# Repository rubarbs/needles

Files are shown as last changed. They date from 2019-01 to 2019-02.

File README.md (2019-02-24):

Needles
is a 1U Eurorack Midi Controller and Mutable Instruments Yarns Companion.

This module was designed to take full advantage of Yarn's capabilities. Most of Yarn's menu settings can be accessed and changed directly from Needles front panel, allowing for very fast and intuitive workflow.

needles

See the guides for more info.

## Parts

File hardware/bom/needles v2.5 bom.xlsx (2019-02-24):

NEEDLES v2.5 - BOM
Mouser Cart: https://www.mouser.com/ProjectManager/ProjectDetail.aspx?AccessID=fd577facc3
Parts | Qty | Description | Value | Package | MOUSER PART #
RESISTORS / CAPS
R27, R28 | 2 | RESISTOR, 1% | 51 Ohm | 0603 | 652-CR0603FX-51R0ELF
R13, R14 | 2 | RESISTOR, 1% | 1K | 0603 | 652-CR0603FX-1001ELF
R9, R12, R17, R18 | 4 | RESISTOR, 1% | 10K | 0603 | 652-CR0603FX-1002ELF OR 667-ERJ-3EKF1002V
R10, R11 | 2 | RESISTOR, 1% | 4.7K | 0603 | 652-CR0603FX-4701ELF
R15, R16, R19, R20, R21, R22, R23, R47, R48, R51, R52, R53, R54, R55, R56, R57, R58, R59, R60, R61, R62, R63, R68 | 23 | RESISTOR, 1% | 220 Ohm | 0603 | 652-CR0603FX-2200ELF
C2, C3 | 2 | CAPACITOR, ceramic | 22pf | 0603 | 81-GRM185C1H220JA01J or 80-C0603C220J5G7411
C1, C4, C5, C8, C9 | 5 | CAPACITOR, ceramic | 100n | 0603 | 81-GRM188R61C104KA1D
C6, C7 | 2 | CAPACITOR, electrolytic | 22u | PANASONIC C | 667-EEE-FP1E220AR
ICS / OTHER
L1 | 1 | Ferrite Bead |  | 0603 | 710-742792642
D2 | 1 | 1N5819HW diode | 1N5819HW | SOD123 | 621-1N5819HW-F
IC1, IC2, IC3 | 3 | MCP23017-E/SS I/O expander | MCP23017SS | SSOP28 | 579-MCP23017-E/SS
IC5 | 1 | LM1117-3.3V LDO Vreg | REG1117 | SOT223 | 926-LM1117MPX3.3NOPB
IC6 | 1 | CD4051 8-1 multiplexer | 4051PW | TSSOP16 | 595-CD4051BPWR
Y1 | 1 | 16MHz Crystal | 16MHz | CRYSTAL-SMD-5X3.2-4PAD | 815-ABM3B-16-B2
U1 | 1 | ATMega328p | ATMEGA328P | TQFP32-08 | 556-ATMEGA328P-AU
Q1, Q2 | 2 | 2n3906 Transistor | MMBT3906LT1G | MMBT3906LT1G | 863-MMBT3906LT1G
SWITCHES / BUTTONS
SW1 | 1 | Push-button, Yellow | Rest | C&K - Yellow | 611-D6R30F1LFS
SW2 | 1 | Push-button, Blue | Tie | C&K - Blue | 611-D6R60F1LFS
SW3 | 1 | Push-button, Green | Slide | C&K - Green | 611-D6R50F1LFS
SW4, SW5, SW6, SW7, SW8, SW9, SW10, SW11, SW12, SW13, SW14, SW15, SW16, SW17, SW18, SW19, SW20, SW21, SW24, SW25 | 20 | Push-button | 18 Keyboard 2 Octave | E-switch TL2201OAYA | 612-TL2201
SW Caps - Keyboard - 11 white / 7 Gray | 18 | Cap Round - 3.3mm shaft size | Keyboard caps | C&K | black 611-21125, white 611-F0202, gray 611-F0204
SW Caps - Octave - 2 red | 2 | Cap Rectangle - 3.3mm shaft size | octave | C&K | 611-F1203 (OR Selco PB 07/50/000)
S1, S2, S3, S7 | 5 | Tact Switch, 6mm | midi, legato, 3, 7, xtra | E-Switch - TL1105SPF160Q | 612-TL1105SP
Tact Switch Caps | 5 | Tact Caps 2.8mm shaft size | midi, legato, 3, 7, xtra |  | SELCO PB 10/51/000 - these are longer
S4 | 1 | Pushbutton - SPST - w/ LED | Shift | E-Switch - LP15S1WHTRED-N | 612-LP15S1WHTRED-N
S6 | 1 | Toggle switch, on-off-on | OSC-DEF-4T | C&K | 5mm actuator: 611-1103M2S3CQE2 12mm actuator: 611-1103M2S6CBE2 or NKK 633-M201303 (but needs round panel cutout)
LED
LED1, LED2, LED3, LED4, LED5, LED9 | 6 | LED 3mm, Red/Green, 3 terminals | Octave, arp |  | 604-WP115VEGW
LED8 | 1 | LED 3mm, 2 terminals | Legato |  | Red - 604-WP710A10ID, Green - 604-WP710A10GD
DISP1 | 1 | 7 Segment Display Green | Values |  | 755-LA-401MD OR 630-HDSP-F501
DISP2 | 1 | 7 Segment Display Red | Midi Channel |  | 755-LA-401VD OR 630-HDSP-F151
POTENTIOMETERS
R1, R2, R3, R4, R5, R6, R7, R8 | 8 | 10k linear pot, 25mm shaft with marker | 10K |  | Erthenvar , Thonk (https://erthenvar.myshopify.com/collections/9mm-potentiometers/products/9mm-vertical-panel-trimmer#)
VR1 | 1 | Slide Potentiometer | 10k |  | 652-PTA20432015CPB10
Slider cap | 1 | Slider Cap | optional |  | White - 633-AT4003B / Red - 633-AT4003C / Yellow - 633-AT434E
VARIOUS
J1, J3 | 2 | 2x3 Male Header 2.54mm | Power and ICSP | Amphenol/FCI | 649-67996-172HLF (this one is 2x36)
JP2 | 1 | 1x3 Male Header 2.54mm | MIDI |  | 649-77311-118-03LF (3 pin) 649-77311-118-24LF (24 pin)
Female Headers | 2 | 12x5 Female SMD Header | For displays |  | 517-9662102000ARPR
Servo cable | 1 | Female to Male | MIDI out —> Yarns MIDI In | Adafruit | 485-972
H1, H2, H3, H4, H5, H6, H7, H8, H9, H10 | 9 | Hex Stand Off 12mm x 5mm |  | Harwin | 4-40: 855-R44-1001202 M2.5: 855-R25-1001202
Screws for Stand offs | 18 | Flat Head screws |  | Mcmaster | 4-40: https://www.mcmaster.com/#96640A054 M2.5: https://www.mcmaster.com/91698a242

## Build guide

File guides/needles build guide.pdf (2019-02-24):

## NEEDLES v2.5 DIY Build Instructions

Hi, thanks for building this module. Please go through this entire doc prior to building, especially the pictured steps below. Some components need some prep before soldering and some should be soldered with the panel screwed in so that they align correctly and are the correct height off the PCB. I solder in this order starting with SMD:

- All IC’s (both sides of pcb)
- Resistors
- Caps
- Thru-hole headers (facing the bottom)
- Upload software
- Check 3.3v
- Keyboard/Octave switches (After gluing caps. Must be flush with PCB. Solder one leg, then while pressing down on the switch, heat the leg again to make sure switch is flush with pcb. Solder the rest of the legs.
- The rest of the components following the pictured tips below:

SCROLL DOWN

\ | /
\ | /
\/

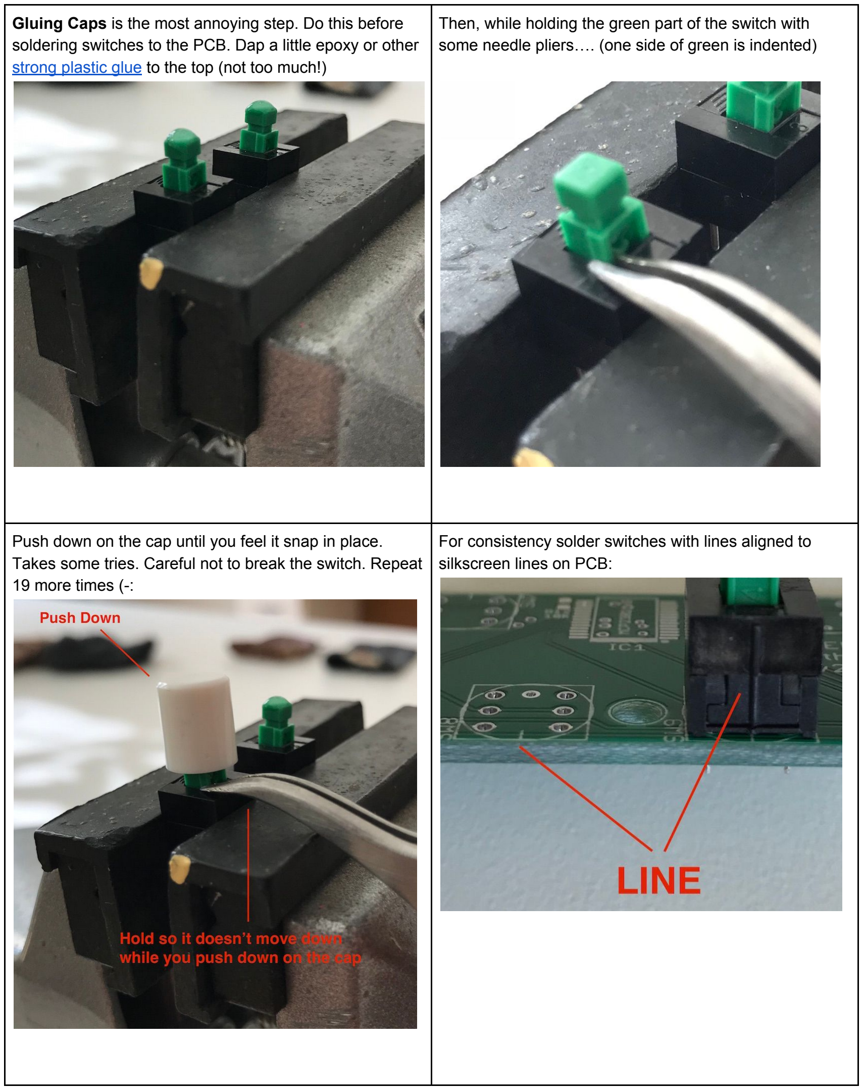
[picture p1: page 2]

Gluing Caps is the most annoying step. Do this before soldering switches to the PCB. Dap a little epoxy or other strong plastic glue (https://www.amazon.com/J-B-Weld-50132-PlasticWeld-Quick-Setting/dp/B009EU5ZMK?s=automotive) to the top (not too much!)

Then, while holding the green part of the switch with some needle pliers…. (one side of green is indented)

Push down on the cap until you feel it snap in place. Takes some tries. Careful not to break the switch. Repeat 19 more times (-:

For consistency solder switches with lines aligned to silkscreen lines on PCB:

Led Segments. You might think of a different technique. It’s possible to skip the female headers and just solder the male headers to the perf board. Play around with it if you like.
Locate parts and repeat these steps for both
segments. I sent the perf board thingies with the pcb

Stack parts. Solder the 10 legs, joining segment and male headers together. Making sure all the pieces are perfectly flush! Solder one leg, then while pressing down, heat the leg again to make sure it’s all flush. Solder the remaining legs.

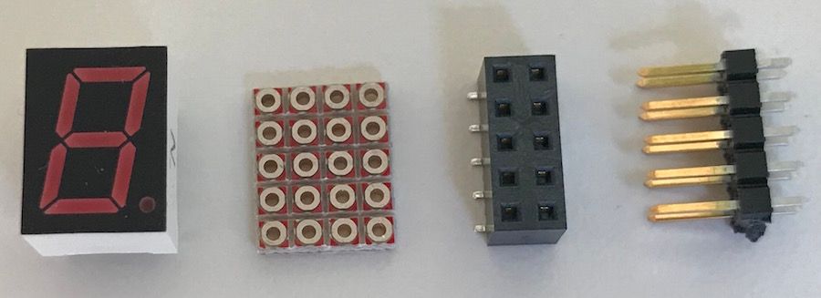
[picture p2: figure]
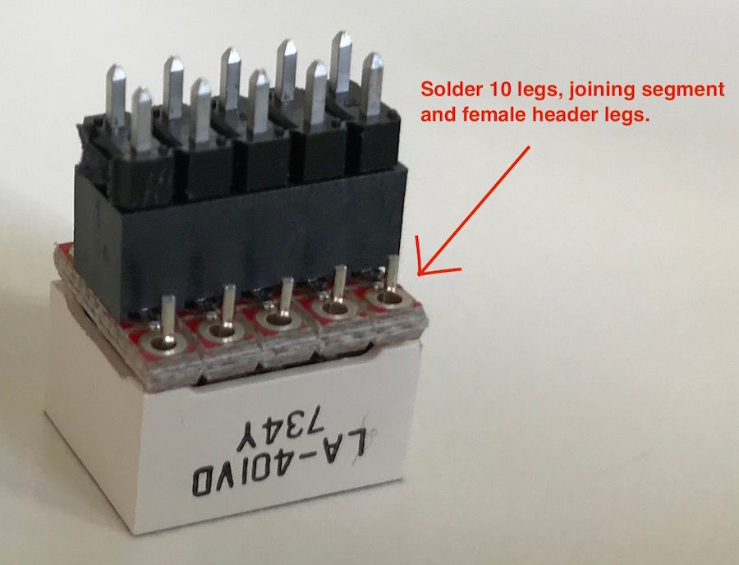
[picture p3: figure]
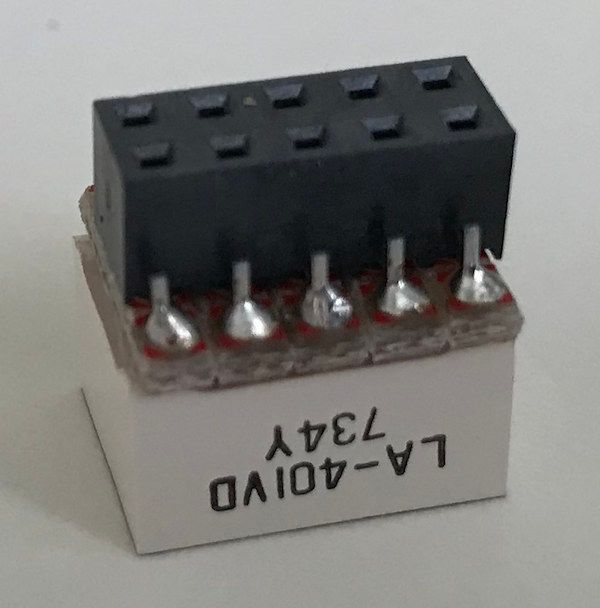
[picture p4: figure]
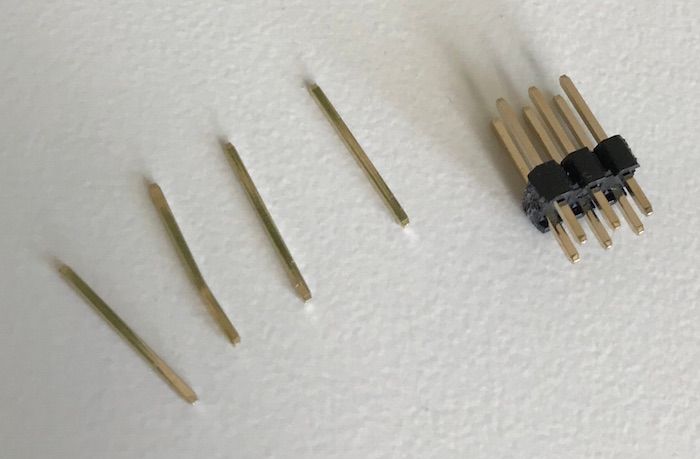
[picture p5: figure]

Remove 10 pin header: | Take out 10 header pins from the male header.

Push segment gently into panel so it’s flat with the panel front:

Secure panel to PCB. Insert the loose headers you removed one by one into the segment’s female header. Make sure again the segment is sitting flat, and solder headers.

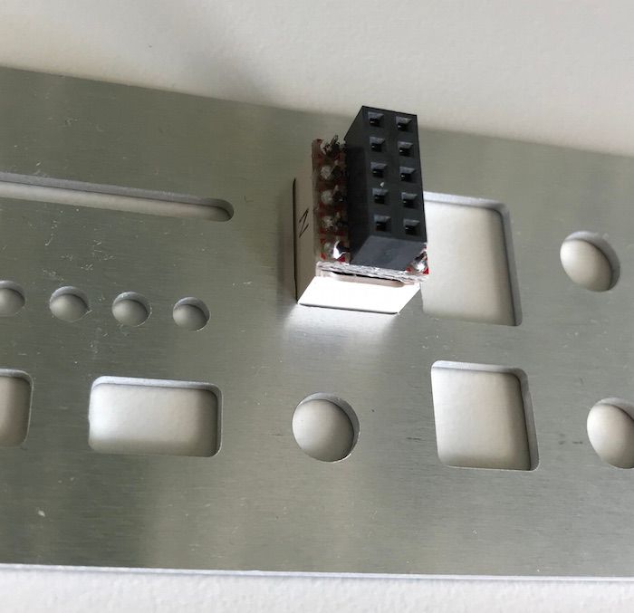
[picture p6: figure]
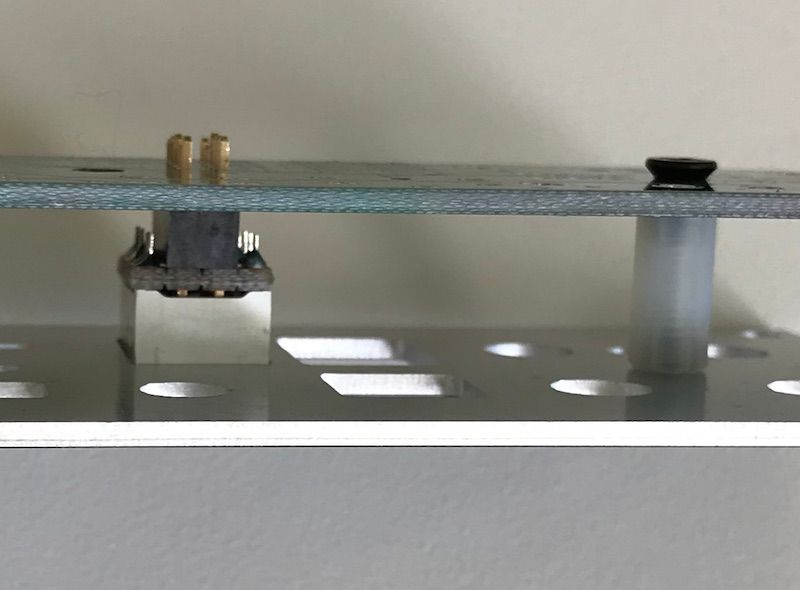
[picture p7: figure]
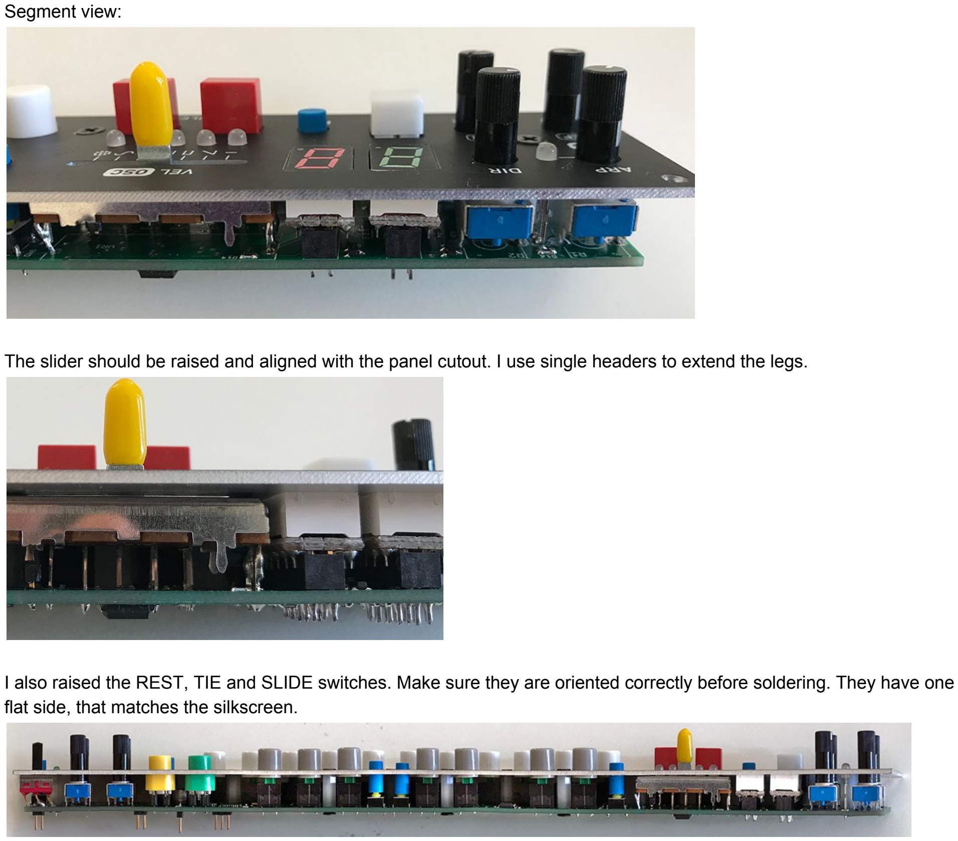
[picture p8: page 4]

Segment view:

The slider should be raised and aligned with the panel cutout. I use single headers to extend the legs.

I also raised the REST, TIE and SLIDE switches. Make sure they are oriented correctly before soldering. They have one flat side, that matches the silkscreen.

Back of PCB. Servo motor cable going to Yarns MIDI IN. Power says +5V but you can give it +12V.

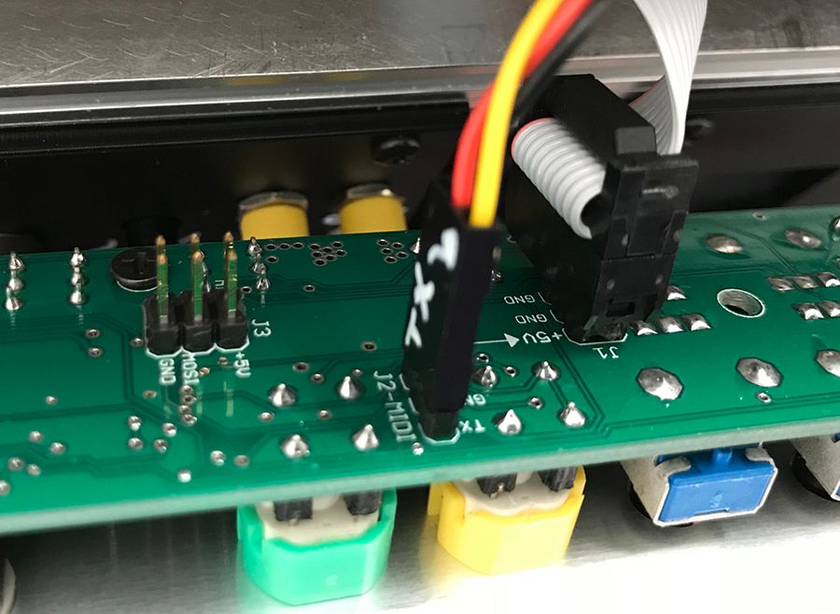
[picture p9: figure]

I solder MIDI wires to the back of Yarns. You could make a little 1U panel with a MIDI jack and connect to the front:

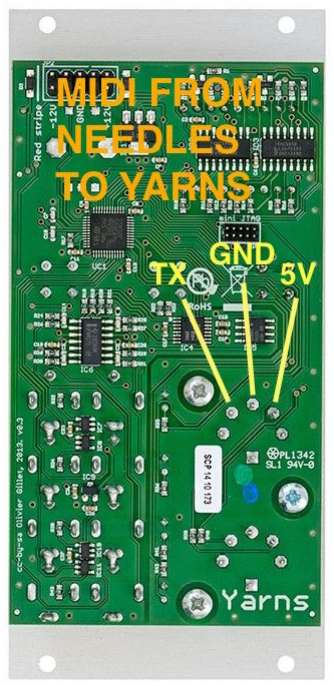
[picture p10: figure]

Software:
Written in Arduino. Download “Needles_v2.4_2.ino” located in the Software folder. Download two libraries for Arduino using the Library Manager or directly - the MIDI Library, (https://github.com/FortySevenEffects/arduino_midi_library/releases/tag/4.3.1) and Adafruit MCP23017 Library. (https://github.com/adafruit/Adafruit-MCP23017-Arduino-Library) Place them in the correct folders. Connect your programmer to the ICSP Header. (I use an Olimex AVR ISP MKII).
Choose Arduino/Genuino UNO Board (Ensures the correct fuses are set)

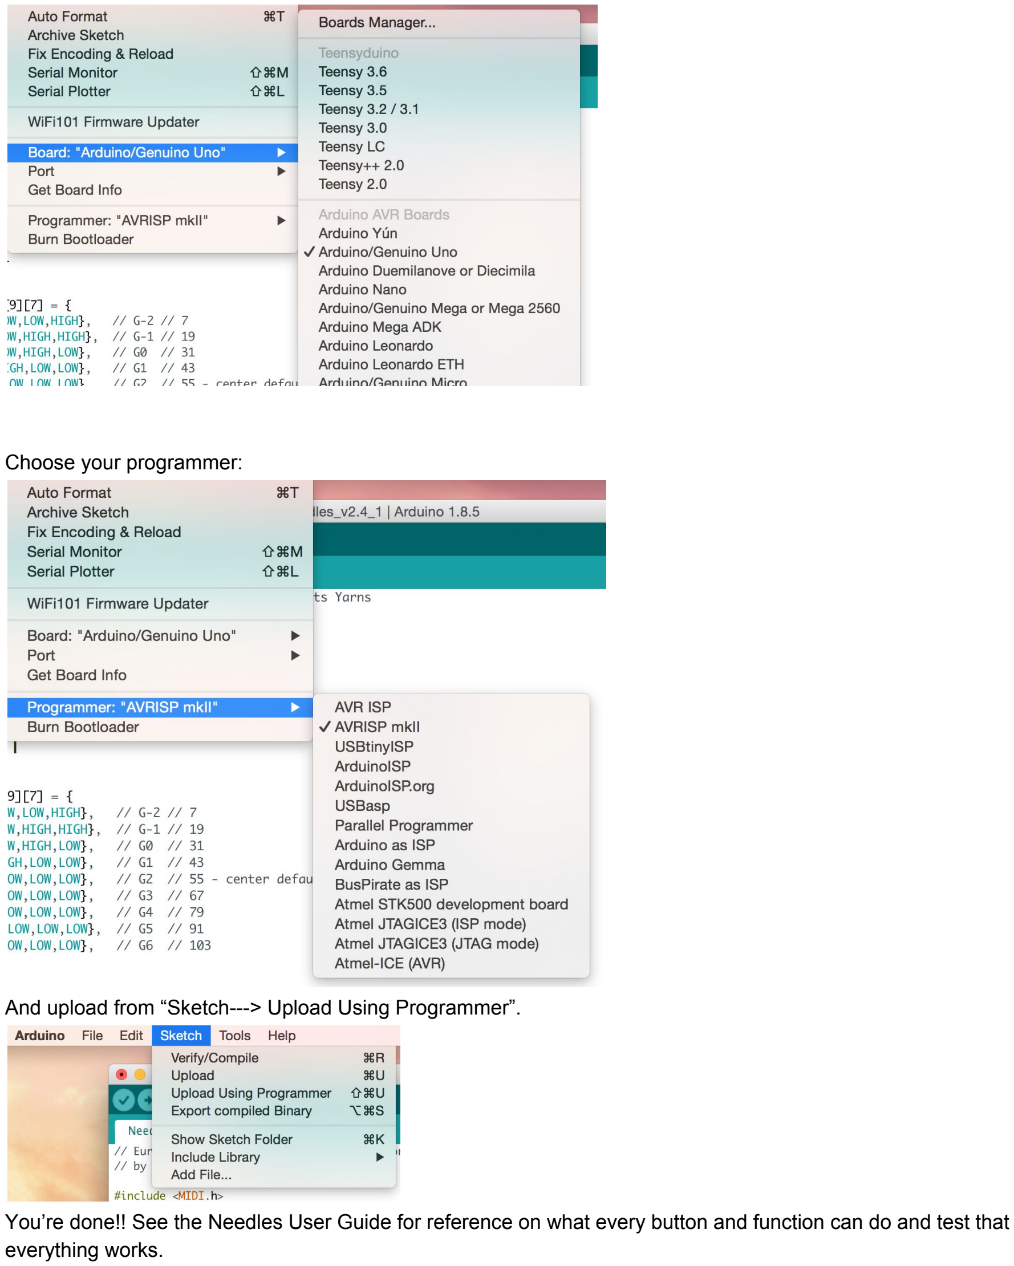
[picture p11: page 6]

Choose your programmer:

And upload from “Sketch---> Upload Using Programmer”.

You’re done!! See the Needles User Guide for reference on what every button and function can do and test that everything works.

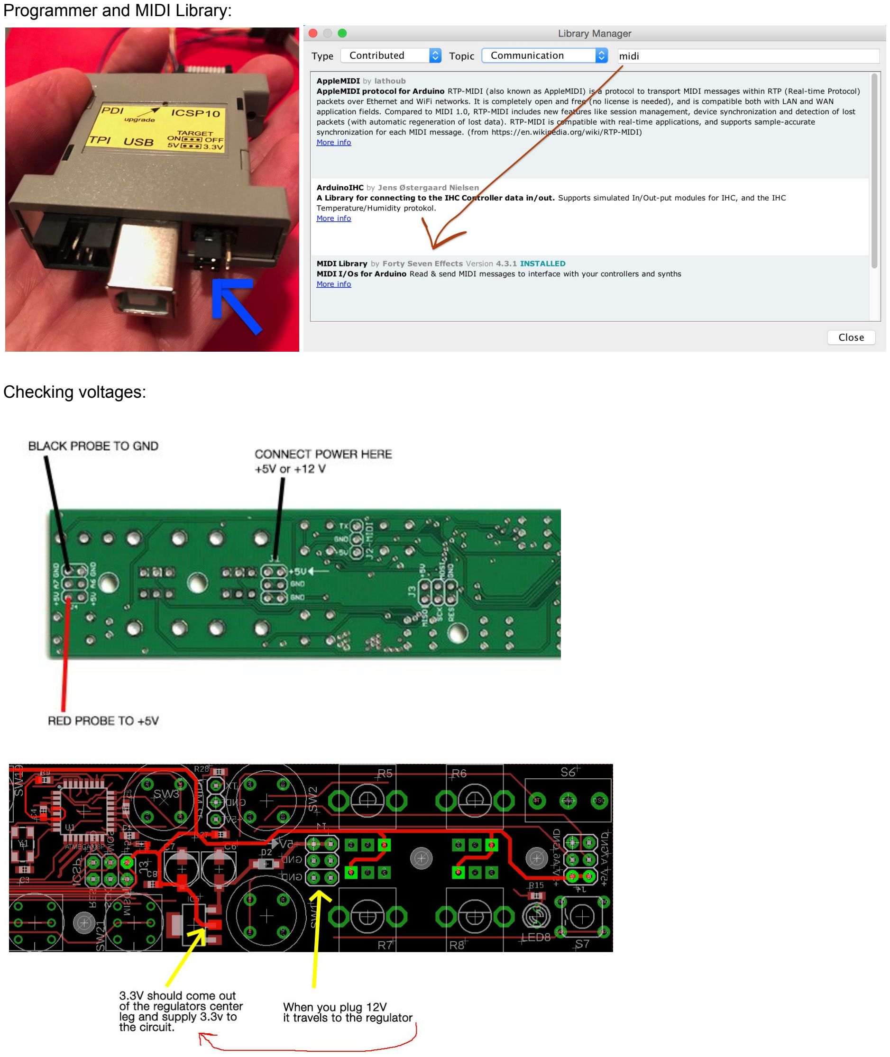
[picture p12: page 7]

Programmer and MIDI Library:

Checking voltages:

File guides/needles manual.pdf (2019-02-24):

Needles v2.5 Manual

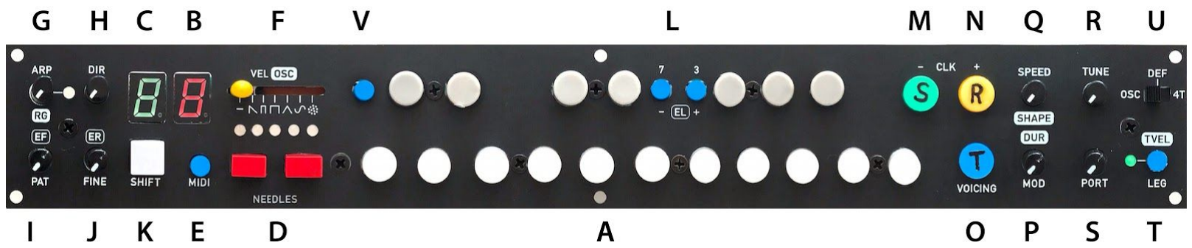
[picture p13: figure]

A. Keyboard: G2-C4. Full range is G-2 to C8. Will also transpose any recorded sequence. See “MIDI” for latching
B. Red: MIDI channel segment. 1-4.
C. Green: Values segment.
D. Octaves: 4 up and 4 down. Press both Octave buttons at the same time to return to center.
E. MIDI - Channel selection 1-4. Pressing MIDI button while holding down note/notes will latch those notes. SHIFT will light up. To unlatch return to the latched MIDI channel and press any octave key. Temporary hack.
F. VEL/OSC - Velocity 0-127. In 1M mode velocity is recorded into a sequence and output on Yarns CV2. Try recording a different velocity for each note in your sequence and using CV2 output to modulate something. When “OSC mode” is on slider changes to Waveform selection.
G. ARP - Range “0-4”. “0” is off. Turns on at “1” with red LED. Turning with SHIFT turns on “Euclidean mode” with green LED. In “4T mode” used to turn on RG - Rhythm Generator.
H. DIR - Arp direction. Used also in “Euclidean mode”
I. PAT - Arp Pattern “1-22”. In “Euclidean mode” chooses Euclidean Fill “0-32”.
J. FINE - Fine tuning. In “Euclidean mode” chooses Euclidean Rotate “0-32".
K. SHIFT - Special functions and Latch indicator
L. 3 & 7 - When recording sequences in Yarns these will insert 3 or 7 ties. Together with SHIFT will insert 3 or 7 rests. In “Euclidean mode” will choose Euclidean Length -/+
a. 3 & 7 explained: Press “Record” on Yarns to record a sequence. It shows “step 01”
i. Insert any note in “step 01” from Needles.
ii. | Press “3”. You inserted 3 ties. Yarns will be on “step 5”.
iii. | Insert any note.
iv. | Press “7”. You inserted 7 rests. Yars will be on “step 13”.
v. Press “3”. You inserted 3 ties. Yarns will be on step “17”.
vi. | Press Record on Yarns exit recording. You recorded a 16 step sequence. This is how you can
| record sequences in Yarns super fast!
| 3 | | 7 | | 3
note | tie | tie | tie | note | tie | tie | tie | tie | tie | tie | tie | note | tie | tie | tie
1 | 2 | 3 | 4 | 5 | 6 | 7 | 8 | 9 | 10 | 11 | 12 | 13 | 14 | 15 | 16

vii. | Try inserting a kick on step 1, 5, 9, 13 by pressing 3 in between each one and exiting Yarns
| record mode on step 17. Takes 3 seconds (-:
M. SLIDE - Inserts a Slide. Legato must be turned on. Together with SHIFT chooses Sequence Clock Division “-”
N. REST - Inserts a Rest. Together with SHIFT chooses Sequence Clock Division “+”
O. TIE - Inserts a Tie. Together with SHIFT chooses Voicing (2P, 4P, 2>, 4>, 8>)
P. MOD - Vibrato. Independant for each channel. In “4T Mode” chooses Trigger Duration
Q. SPEED - Vibrato Speed. Independant for each channel. In “4T Mode” chooses Trigger Shape
R. TUNE - Tuning System 0-33.
S. PORT - Portamento. Only when Legato is off.
T. LEG - Legato on/off with LED indicator. Turn on for Slides. In “4T Mode” turns on Trigger Velocity Scale, used with Velocity Slider
U. OSC - DEF - 4T:
a. Default mode in center.
b. 4T mode changes SPEED, MOD, LEG, ARP to send 4T specific values. Remember that triggers in 4T come out of the Yarns CV outputs. Set the NO(TE) parameter to the trigger note you want for each Part. Default is “36, 38, 40, 42”. I recommend setting it to “60, 62, 64, 65” which means C3, D3, E3, F3 which is the center octave setting on Needles. Save your Layouts in Yarns too.
c. OSC mode turns on an oscillator and loads a Saw waveform to as many channels as your current Yarns setup allows. Velocity slider chooses between the waveform. For example:
i. On CV4 in monophonic mode (1M)
ii. | On CV3 and CV4 in duophonic modes (2M or 2P)
iii. | On CV1, CV2, CV3, CV4 in quadraphonic modes (4M or 4P)
This is great for using Yarns as a 4 channel oscillator module (each channel having it’s own unique waveform), or for fattening up sounds when sequencing in 1M and 2M modes - because CV3 or CV4 will play the exact same sequence that is recorded and sent out of CV1 and CV2.. So you can flip the OSC switch anytime and viola - you get one or two extra voices.
V. XTRA - button for something of your choice.

YARNS MIDI IMPLEMENTATION CHART: https://docs.google.com/spreadsheets/d/15TJX1dSbiRo1jPDxPYR4GV2ICQuVu5B6wAjiAAwP60o/pub?gid=1

Most of Yarns settings can be accessed from Needles. But to record sequences you need to work together with Yarns to enter “Record mode”. Choose the Layout you want in Yarns (1M, 2M, 4M etc..), and then choose if you want each Part to receive messages it’s own unique channel messages. For example, if you want Needles to control 4 different and unique channels:
- choose 4M layout on Yarns
- Set Part 1 to receive on Channel 1 - Needles channel 1 will control it
- Set Part 2 to receive on Channel 2 - Needles channel 2 will control it
- Set Part 3 to receive on Channel 3 - Needles channel 3 will control it
- Set Part 4 to receive on Channel 4 - Needles channel 4 will control it

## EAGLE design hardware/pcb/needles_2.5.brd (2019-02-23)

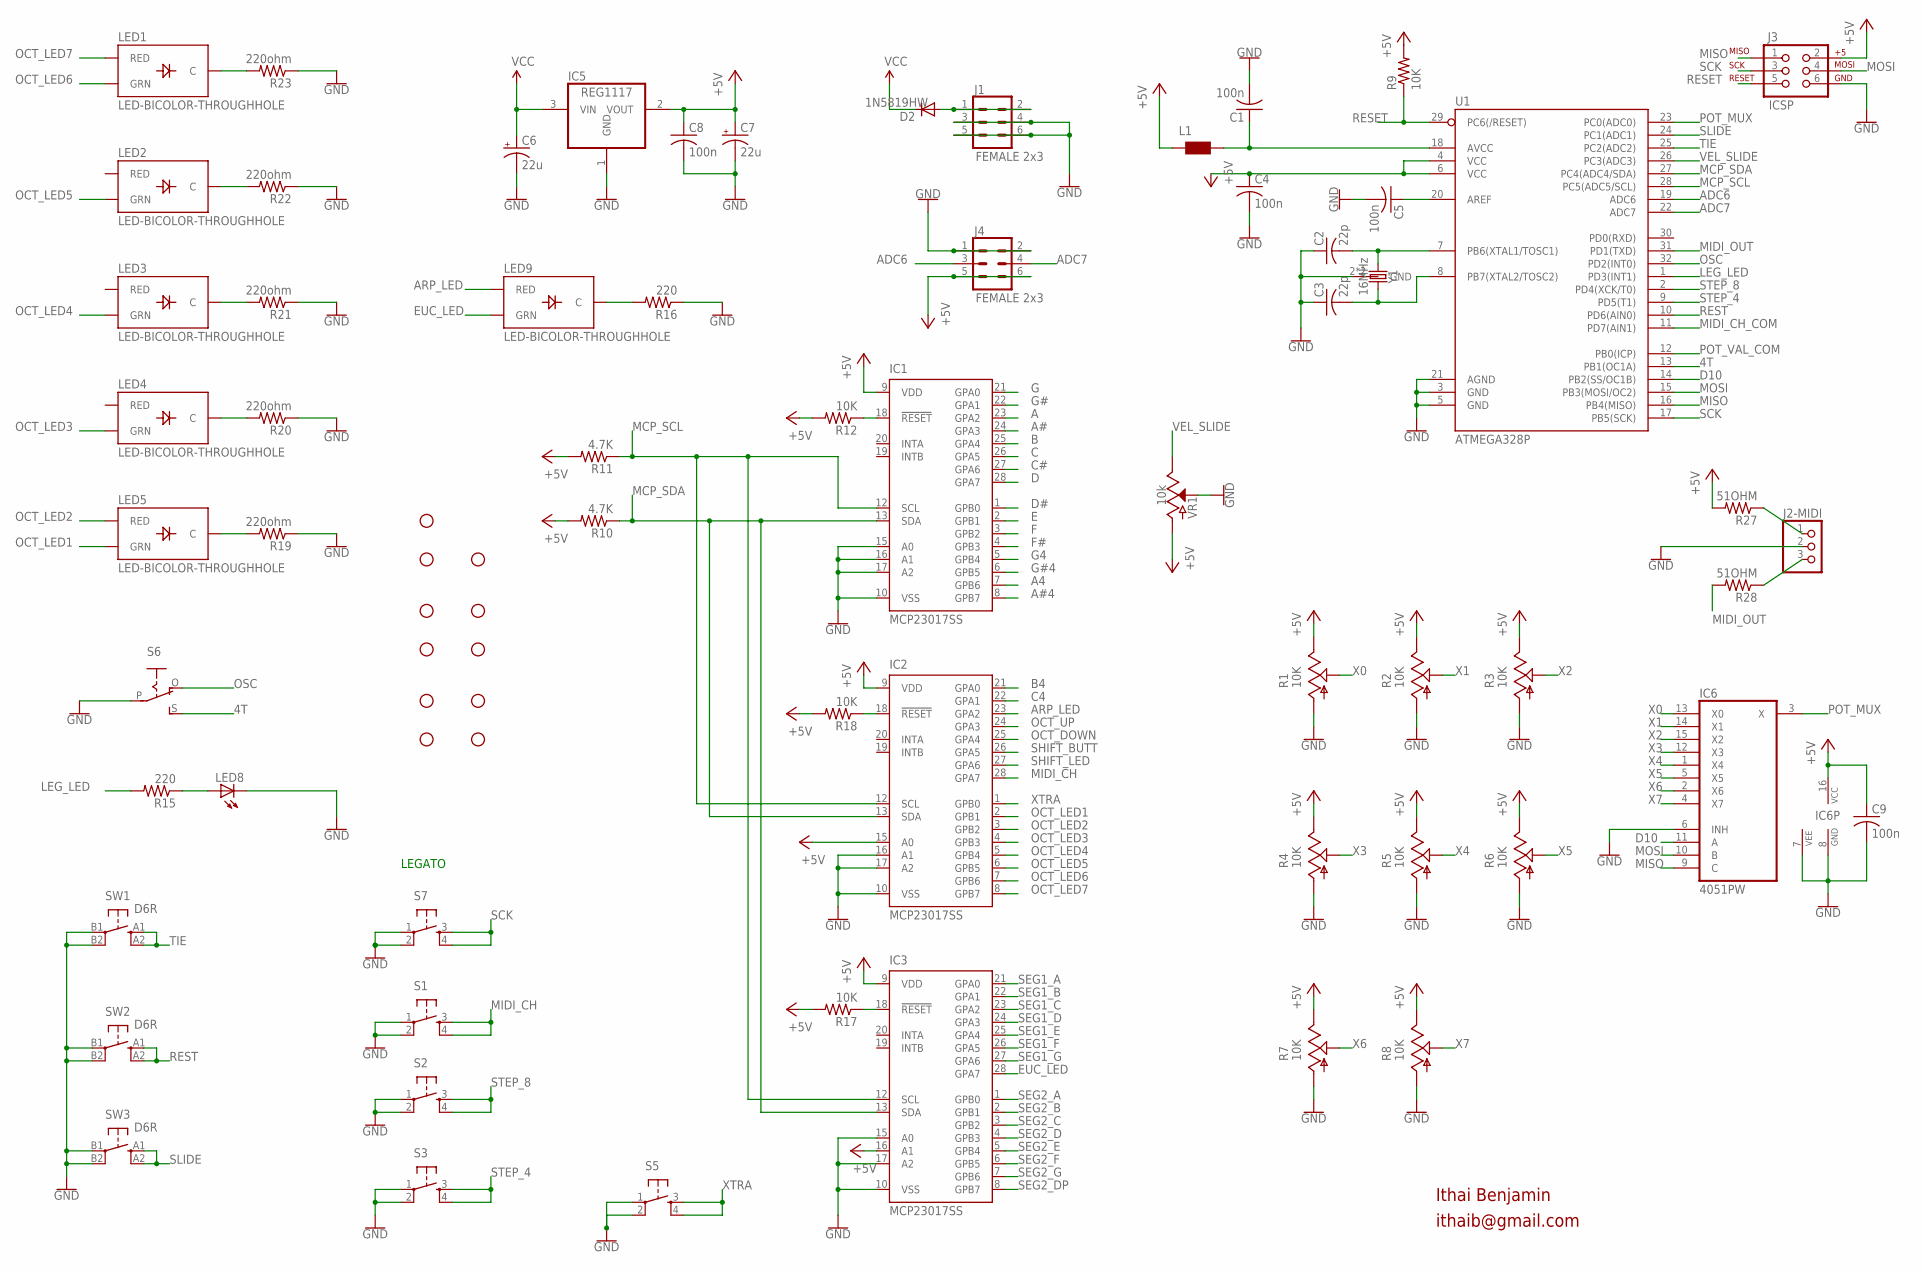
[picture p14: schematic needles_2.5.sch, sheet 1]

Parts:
C1, C4, C5, C8, C9: 100n; C0603
C2, C3: 22p; C0603
C6, C7: 22u; PANASONIC_C
D2: 1N5819HW; SOD123
H1, H2, H3, H4, H5, H6, H7, H8, H9, H10, H11: STAND-OFF
IC1, IC2, IC3: MCP23017SS; SSOP28
IC5: REG1117; SOT223
IC6: 4051PW; TSSOP16
J1, J4: FEMALE 2x3; 2X3
J2-MIDI: PINHD-1X3; 1X03
J3: ICSP; 2X3
L1: WE-CBF_0603; 0603
LED1, LED2, LED3, LED4, LED5, LED9: LED-BICOLOR-THROUGHHOLE
LED8: LED3MM
R1, R2, R3, R4, R5, R6, R7, R8: 10K; ALPS_POT_VERTICAL
R9, R12, R17, R18: 10K; R0603
R10, R11: 4.7K; R0603
R15, R16: 220; R0603
R19, R20, R21, R22, R23: 220ohm; R0603
R27, R28: 51OHM; R0603
S1, S2, S3, S5, S7: TAC_SWITCHPTH; TACTILE-PTH
S6: S-ON-ONSMALL_SLIDE; ES_100SP1T6B11M2QEH_SMALL
SW1, SW2, SW3: D6R
U1: ATMEGA328P; TQFP32-08
VR1: 10k; SLIDER-MEDIUM
Y1: 16MHz; CRYSTAL-SMD-5X3.2-4PAD

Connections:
4T: S6.S, U1.13 (PB1(OC1A))
+5V: C4.1, C7.+, C8.1, C9.1, IC1.9 (VDD), IC2.9 (VDD), IC2.15 (A0), IC3.9 (VDD), IC3.16 (A1), IC5.2 (VOUT), IC6.16 (VCC), J3.2, J4.5, J4.6, L1.1, R1.P$1 (E), R2.P$1 (E), R3.P$1 (E), R4.P$1 (E), R5.P$1 (E), R6.P$1 (E), R7.P$1 (E), R8.P$1 (E), R9.2, R10.2, R11.2, R12.2, R17.2, R18.2, R27.2, U1.4 (VCC), U1.6 (VCC), VR1.BOTTOM (A); also elsewhere on the board
A: IC1.23 (GPA2); also elsewhere on the board
A4: IC1.7 (GPB6); also elsewhere on the board
A#: IC1.24 (GPA3); also elsewhere on the board
A#4: IC1.8 (GPB7); also elsewhere on the board
ADC6: J4.3, U1.19 (ADC6)
ADC7: J4.4, U1.22 (ADC7)
AREF: C5.1, U1.20 (AREF)
ARP_LED: IC2.23 (GPA2), LED9.3 (RED)
B: IC1.25 (GPA4); also elsewhere on the board
B4: IC2.21 (GPA0); also elsewhere on the board
C: IC1.26 (GPA5); also elsewhere on the board
C4: IC2.22 (GPA1); also elsewhere on the board
C#: IC1.27 (GPA6); also elsewhere on the board
D: IC1.28 (GPA7); also elsewhere on the board
D10: IC6.11 (A), U1.14 (PB2(SS/OC1B))
D#: IC1.1 (GPB0); also elsewhere on the board
E: IC1.2 (GPB1); also elsewhere on the board
EUC_LED: IC3.28 (GPA7), LED9.1 (GRN)
F: IC1.3 (GPB2); also elsewhere on the board
F#: IC1.4 (GPB3); also elsewhere on the board
G: IC1.21 (GPA0); also elsewhere on the board
G4: IC1.5 (GPB4); also elsewhere on the board
G#: IC1.22 (GPA1); also elsewhere on the board
G#4: IC1.6 (GPB5); also elsewhere on the board
GND: C1.2, C2.1, C3.1, C4.2, C5.2, C6.-, C7.-, C8.2, C9.2, IC1.10 (VSS), IC1.15 (A0), IC1.16 (A1), IC1.17 (A2), IC2.10 (VSS), IC2.16 (A1), IC2.17 (A2), IC3.10 (VSS), IC3.15 (A0), IC3.17 (A2), IC5.1 (GND), IC6.6 (INH), IC6.7 (VEE), IC6.8 (GND), J1.3, J1.4, J1.5, J1.6, J2-MIDI.2, J3.6, J4.1, J4.2, LED8.K (C), R1.P$3 (A), R2.P$3 (A), R3.P$3 (A), R4.P$3 (A), R5.P$3 (A), R6.P$3 (A), R7.P$3 (A), R8.P$3 (A), R16.1, R19.1, R20.1, R21.1, R22.1, R23.1, S1.1, S1.2, S2.1, S2.2, S3.1, S3.2, S5.1, S5.2, S6.P, S7.1, S7.2, SW1.B1, SW1.B2 (P1), SW2.B1, SW2.B2 (P1), SW3.B1, SW3.B2 (P1), U1.3 (GND), U1.5 (GND), U1.21 (AGND), VR1.WIPER (S), Y1.2 (GND), Y1.4 (GND); also elsewhere on the board
LEG_LED: R15.2, U1.1 (PD3(INT1))
MCP_SCL: IC1.12 (SCL), IC2.12 (SCL), IC3.12 (SCL), R11.1, U1.28 (PC5(ADC5/SCL))
MCP_SDA: IC1.13 (SDA), IC2.13 (SDA), IC3.13 (SDA), R10.1, U1.27 (PC4(ADC4/SDA))
MIDI_CH: IC2.28 (GPA7), S1.3, S1.4
MIDI_CH_COM: U1.11 (PD7(AIN1)); also elsewhere on the board
MIDI_OUT: R28.2, U1.31 (PD1(TXD))
MISO: IC6.9 (C), J3.1, U1.16 (PB4(MISO))
MOSI: IC6.10 (B), J3.4, U1.15 (PB3(MOSI/OC2))
unnamed: IC1.18 (!RESET), R12.1
unnamed: IC2.18 (!RESET), R18.1
unnamed: C1.1, L1.2, U1.18 (AVCC)
unnamed: LED1.2 (C), R23.2
unnamed: C2.2, U1.7 (PB6(XTAL1/TOSC1)), Y1.1
unnamed: C3.2, U1.8 (PB7(XTAL2/TOSC2)), Y1.3 (2)
unnamed: LED2.2 (C), R22.2
unnamed: IC3.18 (!RESET), R17.1
unnamed: LED3.2 (C), R21.2
unnamed: LED4.2 (C), R20.2
unnamed: LED5.2 (C), R19.2
unnamed: J2-MIDI.1, R27.1
unnamed: J2-MIDI.3, R28.1
unnamed: LED8.A, R15.1
unnamed: LED9.2 (C), R16.2
unnamed: D2.A, J1.1, J1.2
OCT_DOWN: IC2.25 (GPA4); also elsewhere on the board
OCT_LED1: IC2.2 (GPB1), LED5.1 (GRN)
OCT_LED2: IC2.3 (GPB2), LED5.3 (RED)
OCT_LED3: IC2.4 (GPB3), LED4.1 (GRN)
OCT_LED4: IC2.5 (GPB4), LED3.1 (GRN)
OCT_LED5: IC2.6 (GPB5), LED2.1 (GRN)
OCT_LED6: IC2.7 (GPB6), LED1.1 (GRN)
OCT_LED7: IC2.8 (GPB7), LED1.3 (RED)
OCT_UP: IC2.24 (GPA3); also elsewhere on the board
OSC: S6.O, U1.32 (PD2(INT0))
POT_MUX: IC6.3 (X), U1.23 (PC0(ADC0))
POT_VAL_COM: U1.12 (PB0(ICP)); also elsewhere on the board
RESET: J3.5, R9.1, U1.29 (PC6(/RESET))
REST: SW2.A1 (S), SW2.A2 (S1), U1.10 (PD6(AIN0))
SCK: J3.3, S7.3, S7.4, U1.17 (PB5(SCK))
SEG1_A: IC3.21 (GPA0); also elsewhere on the board
SEG1_B: IC3.22 (GPA1); also elsewhere on the board
SEG1_C: IC3.23 (GPA2); also elsewhere on the board
SEG1_D: IC3.24 (GPA3); also elsewhere on the board
SEG1_E: IC3.25 (GPA4); also elsewhere on the board
SEG1_F: IC3.26 (GPA5); also elsewhere on the board
SEG1_G: IC3.27 (GPA6); also elsewhere on the board
SEG2_A: IC3.1 (GPB0); also elsewhere on the board
SEG2_B: IC3.2 (GPB1); also elsewhere on the board
SEG2_C: IC3.3 (GPB2); also elsewhere on the board
SEG2_D: IC3.4 (GPB3); also elsewhere on the board
SEG2_DP: IC3.8 (GPB7); also elsewhere on the board
SEG2_E: IC3.5 (GPB4); also elsewhere on the board
SEG2_F: IC3.6 (GPB5); also elsewhere on the board
SEG2_G: IC3.7 (GPB6); also elsewhere on the board
SHIFT_BUTT: IC2.26 (GPA5); also elsewhere on the board
SHIFT_LED: IC2.27 (GPA6); also elsewhere on the board
SLIDE: SW3.A1 (S), SW3.A2 (S1), U1.24 (PC1(ADC1))
STEP_4: S3.3, S3.4, U1.9 (PD5(T1))
STEP_8: S2.3, S2.4, U1.2 (PD4(XCK/T0))
TIE: SW1.A1 (S), SW1.A2 (S1), U1.25 (PC2(ADC2))
VCC: C6.+, D2.C, IC5.3 (VIN)
VEL_SLIDE: U1.26 (PC3(ADC3)), VR1.TOP (E)
X0: IC6.13 (X0), R1.P$2 (S)
X1: IC6.14 (X1), R2.P$2 (S)
X2: IC6.15 (X2), R3.P$2 (S)
X3: IC6.12 (X3), R4.P$2 (S)
X4: IC6.1 (X4), R5.P$2 (S)
X5: IC6.5 (X5), R6.P$2 (S)
X6: IC6.2 (X6), R7.P$2 (S)
X7: IC6.4 (X7), R8.P$2 (S)
XTRA: IC2.1 (GPB0), S5.3, S5.4

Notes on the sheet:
LEGATO
Ithai Benjamin
ithaib@gmail.com

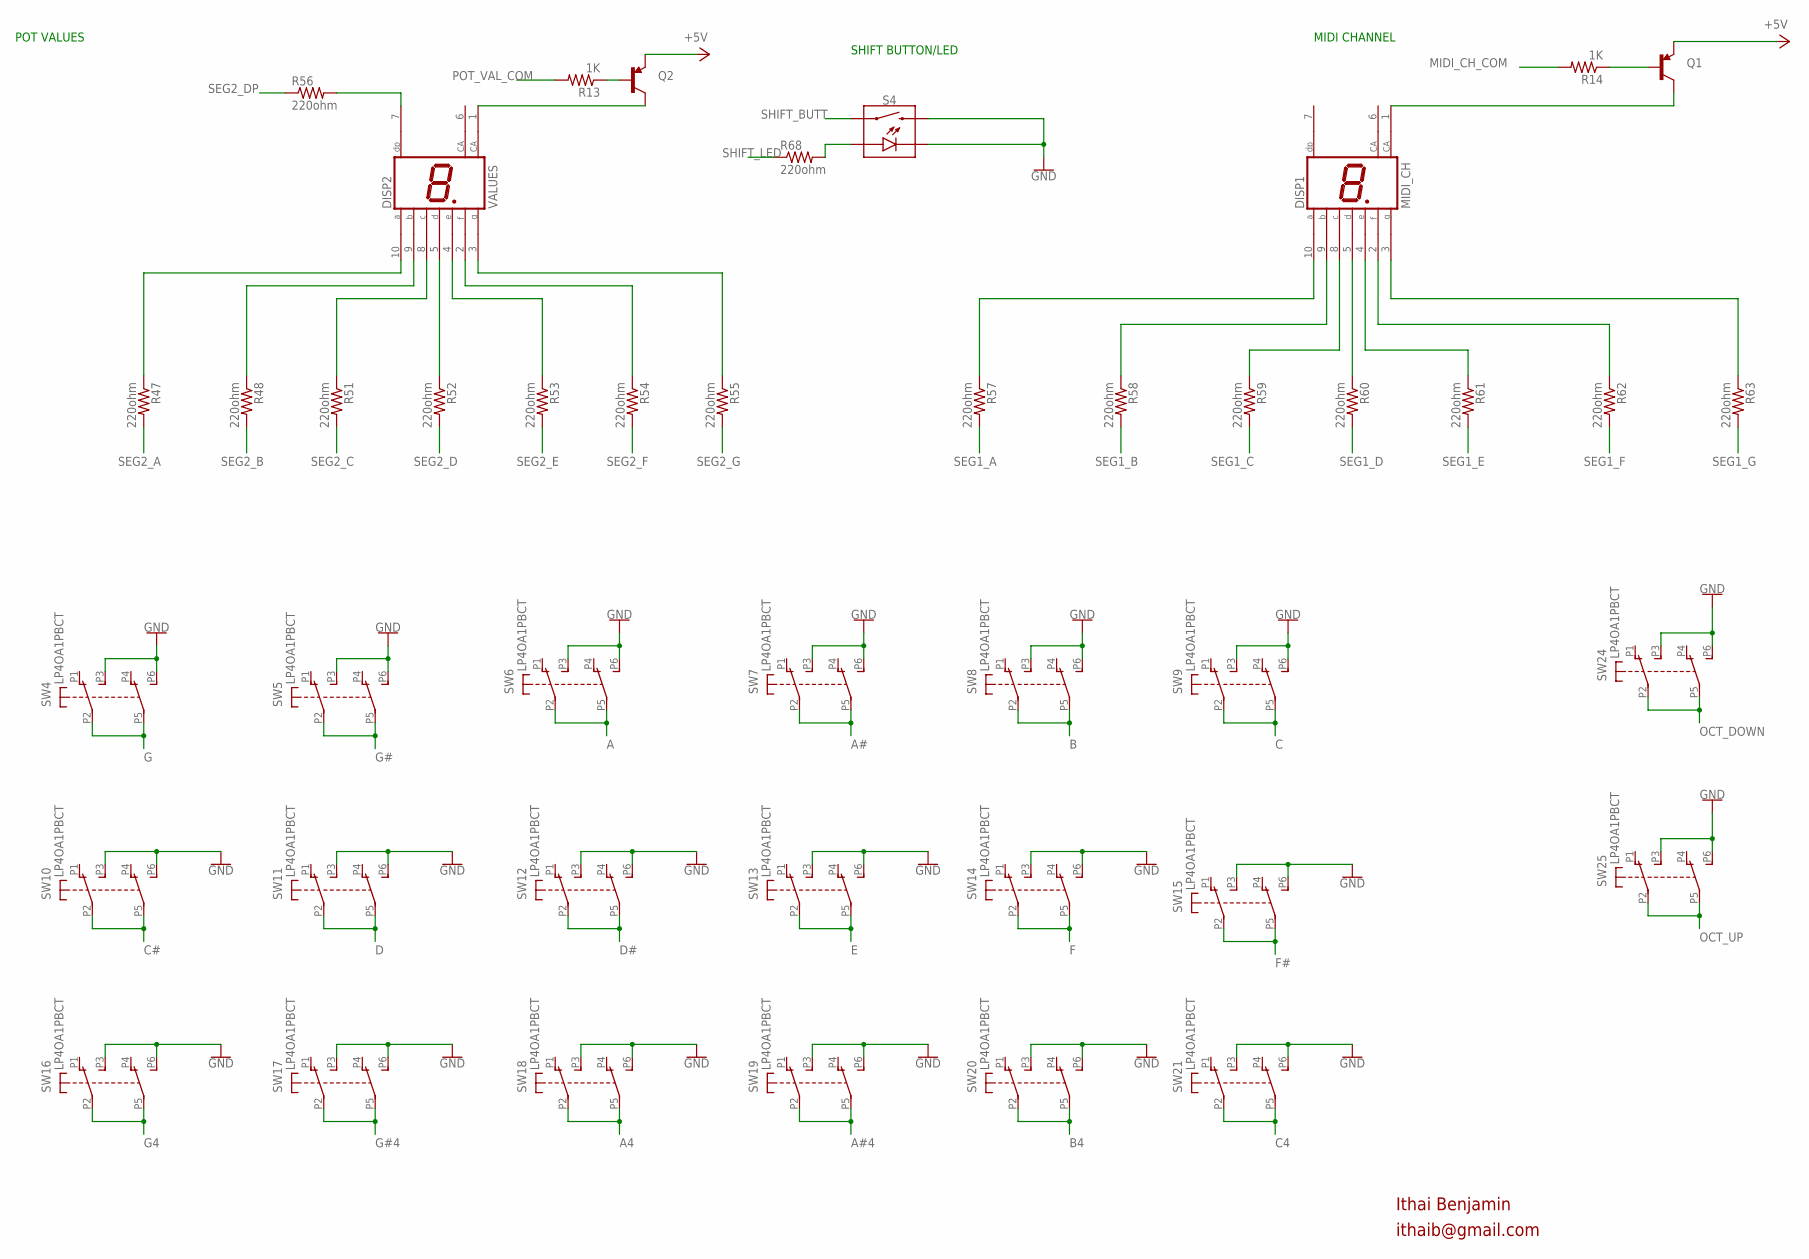
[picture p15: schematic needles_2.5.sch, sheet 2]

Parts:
DISP1: MIDI_CH; DISPLAY-HP_HDSP-E
DISP2: VALUES; DISPLAY-HP_HDSP-E
Q1, Q2: TRANSISTOR_PNPSMD; SOT23-3
R13, R14: 1K; R0603
R47, R48, R51, R52, R53, R54, R55, R56, R57, R58, R59, R60, R61, R62, R63, R68: 220ohm; R0603
S4: MOMENTARY-SWITCH-SPST-LED-PTH-12MM; TACTILE_SWITCH_LED_PTH_12MM
SW4, SW5, SW6, SW7, SW8, SW9, SW10, SW11, SW12, SW13, SW14, SW15, SW16, SW17, SW18, SW19, SW20, SW21, SW24, SW25: LP4OA1PBCT

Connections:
+5V: Q1.2 (E), Q2.2 (E); also elsewhere on the board
A: SW6.P2 (A2), SW6.P5 (B2); also elsewhere on the board
A4: SW18.P2 (A2), SW18.P5 (B2); also elsewhere on the board
A#: SW7.P2 (A2), SW7.P5 (B2); also elsewhere on the board
A#4: SW19.P2 (A2), SW19.P5 (B2); also elsewhere on the board
B: SW8.P2 (A2), SW8.P5 (B2); also elsewhere on the board
B4: SW20.P2 (A2), SW20.P5 (B2); also elsewhere on the board
C: SW9.P2 (A2), SW9.P5 (B2); also elsewhere on the board
C4: SW21.P2 (A2), SW21.P5 (B2); also elsewhere on the board
C#: SW10.P2 (A2), SW10.P5 (B2); also elsewhere on the board
D: SW11.P2 (A2), SW11.P5 (B2); also elsewhere on the board
D#: SW12.P2 (A2), SW12.P5 (B2); also elsewhere on the board
E: SW13.P2 (A2), SW13.P5 (B2); also elsewhere on the board
F: SW14.P2 (A2), SW14.P5 (B2); also elsewhere on the board
F#: SW15.P2 (A2), SW15.P5 (B2); also elsewhere on the board
G: SW4.P2 (A2), SW4.P5 (B2); also elsewhere on the board
G4: SW16.P2 (A2), SW16.P5 (B2); also elsewhere on the board
G#: SW5.P2 (A2), SW5.P5 (B2); also elsewhere on the board
G#4: SW17.P2 (A2), SW17.P5 (B2); also elsewhere on the board
GND: S4.1 (2), S4.2, S4.C, SW4.P3 (A3), SW4.P6 (B3), SW5.P3 (A3), SW5.P6 (B3), SW6.P3 (A3), SW6.P6 (B3), SW7.P3 (A3), SW7.P6 (B3), SW8.P3 (A3), SW8.P6 (B3), SW9.P3 (A3), SW9.P6 (B3), SW10.P3 (A3), SW10.P6 (B3), SW11.P3 (A3), SW11.P6 (B3), SW12.P3 (A3), SW12.P6 (B3), SW13.P3 (A3), SW13.P6 (B3), SW14.P3 (A3), SW14.P6 (B3), SW15.P3 (A3), SW15.P6 (B3), SW16.P3 (A3), SW16.P6 (B3), SW17.P3 (A3), SW17.P6 (B3), SW18.P3 (A3), SW18.P6 (B3), SW19.P3 (A3), SW19.P6 (B3), SW20.P3 (A3), SW20.P6 (B3), SW21.P3 (A3), SW21.P6 (B3), SW24.P3 (A3), SW24.P6 (B3), SW25.P3 (A3), SW25.P6 (B3); also elsewhere on the board
MIDI_CH_COM: R14.2; also elsewhere on the board
unnamed: R68.2, S4.A
unnamed: Q1.1 (B), R14.1
unnamed: Q2.1 (B), R13.1
unnamed: DISP2.1 (CA), Q2.3 (C)
unnamed: DISP2.10 (A), R47.1
unnamed: DISP2.9 (B), R48.1
unnamed: DISP2.8 (C), R51.1
unnamed: DISP2.5 (D), R52.1
unnamed: DISP2.4 (E), R53.1
unnamed: DISP2.2 (F), R54.1
unnamed: DISP2.3 (G), R55.1
unnamed: DISP1.10 (A), R57.1
unnamed: DISP2.7 (DP), R56.2
unnamed: DISP1.1 (CA), Q1.3 (C)
unnamed: DISP1.9 (B), R58.1
unnamed: DISP1.8 (C), R59.1
unnamed: DISP1.5 (D), R60.1
unnamed: DISP1.4 (E), R61.1
unnamed: DISP1.2 (F), R62.1
unnamed: DISP1.3 (G), R63.1
OCT_DOWN: SW24.P2 (A2), SW24.P5 (B2); also elsewhere on the board
OCT_UP: SW25.P2 (A2), SW25.P5 (B2); also elsewhere on the board
POT_VAL_COM: R13.2; also elsewhere on the board
SEG1_A: R57.2; also elsewhere on the board
SEG1_B: R58.2; also elsewhere on the board
SEG1_C: R59.2; also elsewhere on the board
SEG1_D: R60.2; also elsewhere on the board
SEG1_E: R61.2; also elsewhere on the board
SEG1_F: R62.2; also elsewhere on the board
SEG1_G: R63.2; also elsewhere on the board
SEG2_A: R47.2; also elsewhere on the board
SEG2_B: R48.2; also elsewhere on the board
SEG2_C: R51.2; also elsewhere on the board
SEG2_D: R52.2; also elsewhere on the board
SEG2_DP: R56.1; also elsewhere on the board
SEG2_E: R53.2; also elsewhere on the board
SEG2_F: R54.2; also elsewhere on the board
SEG2_G: R55.2; also elsewhere on the board
SHIFT_BUTT: S4.3 (1), S4.4 (1); also elsewhere on the board
SHIFT_LED: R68.1; also elsewhere on the board

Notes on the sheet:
MIDI CHANNEL
POT VALUES
SHIFT BUTTON/LED
Ithai Benjamin
ithaib@gmail.com

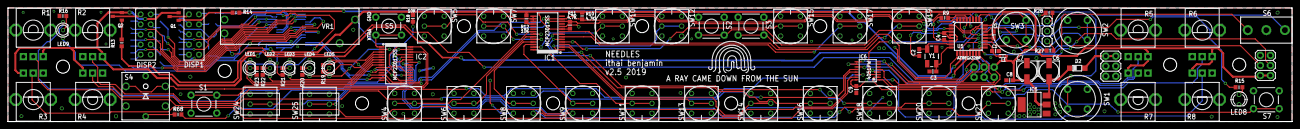
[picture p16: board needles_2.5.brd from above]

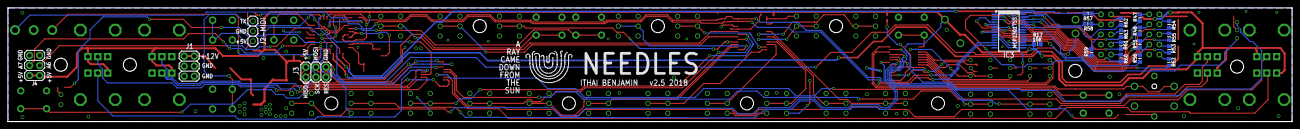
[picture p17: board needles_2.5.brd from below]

Board: 2 copper layers, 324.4 x 28.7 mm, 116 parts (18 on the bottom side), 118 nets.

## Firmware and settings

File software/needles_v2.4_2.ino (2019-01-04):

// Eurorack 1U Midi Keyboard & Controller for Mutable Instruments Yarns
// by Ithai Benjamin v2.4_2 January 2018

#include <MIDI.h>
#include <Wire.h>
#include "Adafruit_MCP23017.h"
Adafruit_MCP23017 mcpArray[3]; // mcpArray[0], mcpArray[1], mcpArray[2],


MIDI_CREATE_DEFAULT_INSTANCE();
#define MIDI_ENABLE 1 

// JUNO Sysex - optional
byte sysexValue[3][7] = { 
  {240, 65, 50, 0, 5, 0, 247}, // cutoff  
  {240, 65, 50, 0, 6, 0, 247}, // res
  {240, 65, 50, 0, 0, 0, 247} // lfo rate
}; 

// Octave leds
char octaveLed_array[9][7] = { 
  {LOW,LOW,LOW,LOW,LOW,LOW,HIGH},   // G-2 // 7
  {LOW,LOW,LOW,LOW,LOW,HIGH,HIGH},  // G-1 // 19
  {LOW,LOW,LOW,LOW,LOW,HIGH,LOW},   // G0  // 31
  {LOW,LOW,LOW,LOW,HIGH,LOW,LOW},   // G1  // 43
  {LOW,LOW,LOW,HIGH,LOW,LOW,LOW},   // G2  // 55 - center default
  {LOW,LOW,HIGH,LOW,LOW,LOW,LOW},   // G3  // 67
  {LOW,HIGH,LOW,LOW,LOW,LOW,LOW},   // G4  // 79
  {HIGH,HIGH,LOW,LOW,LOW,LOW,LOW},  // G5  // 91
  {HIGH,LOW,LOW,LOW,LOW,LOW,LOW},   // G6  // 103
}; 

byte octaveNote_array[9] = {103,91,79,67,55,43,31,19,7};
const int ledPins[7] = {15,14,13,12,11,9,10}; // mcpArray[1]
const int numberOfLED = 7;

// segment display numbers
byte num_array[34][7] = { 
  {0,0,0,0,0,0,1},  // zero
  {1,0,0,1,1,1,1},  // one
  {0,0,1,0,0,1,0},  // two
  {0,0,0,0,1,1,0},  // three
  {1,0,0,1,1,0,0},  // four
  {0,1,0,0,1,0,0},  // five
  {0,1,0,0,0,0,0},  // six
  {0,0,0,1,1,1,1},  // seven
  {0,0,0,0,0,0,0},  // eight
  {0,0,0,0,1,0,0},  // nine
  {1,0,0,1,1,1,1},  // one
  {1,0,0,1,1,1,1},  // one for "11" and so on
  {0,0,1,0,0,1,0},  // two
  {0,0,0,0,1,1,0},  // three
  {1,0,0,1,1,0,0},  // four
  {0,1,0,0,1,0,0},  // five
  {0,1,0,0,0,0,0},  // six
  {0,0,0,1,1,1,1},  // seven
  {0,0,0,0,0,0,0},  // eight
  {0,0,0,0,1,0,0},  // nine
  {0,0,1,0,0,1,0},   // two
  {1,0,0,1,1,1,1},  // one
  {0,0,1,0,0,1,0},   // two
  {0,0,0,0,1,1,0},  // three
  {1,0,0,1,1,0,0},  // four
  {0,1,0,0,1,0,0},  // five
  {0,1,0,0,0,0,0},  // six
  {0,0,0,1,1,1,1},  // seven
  {0,0,0,0,0,0,0},  // eight
  {0,0,0,0,1,0,0},  // nine
  {0,0,0,0,1,1,0},  // three
  {1,0,0,1,1,1,1},  // one
  {0,0,1,0,0,1,0},   // two
  {0,0,0,0,1,1,0}  // three
}; 

// segment display letters
byte letter_array[23][7] = { 
  {0,1,1,1,1,1,1},  // up - arp directions
  {1,1,1,0,1,1,1}, // down
  {0,1,1,0,1,1,1}, // up/down
  {1,1,0,1,1,0,1}, // random
  {0,0,1,1,0,0,0}, // played
  {0,1,1,0,0,0,1}, // chord
  {0,1,0,0,1,0,0}, // S for slide
  {1,1,1,0,0,0,1}, // L for legato
  {1,1,0,0,0,1,0}, // square - trigger shapes
  {1,1,1,0,0,0,1}, // linear
  {0,1,1,0,0,0,0}, // expo
  {0,0,0,0,0,0,1}, // ring
  {1,0,1,1,0,1,0}, // step
  {1,1,0,0,0,0,0}, // burst
  {1,1,1,0,0,0,0}, // t - for trigger velocity scale
  {1,0,0,0,0,0,1}, // v
  {1,1,1,1,1,1,0}, // off
  {0,1,0,0,1,0,0}, // saw
  {0,0,0,1,0,0,1}, // 25% rect
  {1,1,0,0,0,1,0}, // square
  {1,1,1,0,0,0,0}, // tri
  {1,0,1,1,0,1,0}, // sine
  {0,0,0,0,0,0,0}  // noise
}; 

/*
SEGMENTS - Need digitalwrite LOW to turn on. 0 is on 1 is off

1     __A__    10
     |     | 
2   F|     |B  9
     |     |
3     __G__    8
     |     | 
4   E|     |C  7 --> + for DP
     |     |
5     __D__    6 -->DP

A  B   C  D  E  F  G  DP
1  10  8  5  4  2  3  6
*/ 

// Segments
#define onesAnode 7 // atmega - MIDI channel
#define tensAnode 8 // atmega - Values
#define tensDP 15 // Values DP // mcpArray[2]
const int ones[7] = {0,1,2,3,4,5,6}; // mcpArray[2]
const int tens[7] = {8,9,10,11,12,13,14}; // mcpArray[2]
int segOnStart = 0; // tensAnode starts blank regardless of ccPot positions

// segment cc display
byte arpLow[6]  = {3,25,51,76,102,123};
byte arpHigh[6] = {25,51,76,102,123,127};
int directionON=0;
int rangeON=0;
int patternON=0;
int portaON=0;
int trigShapeON=0;
int trigDurationON=0;
int vibratoON=0;
int tuningON=0;
int speedON=0;
int fineTuneON=0;
int oscON=0; // (0-18,19-36,37-54,55-73,74-91,92-109,110-127)
int eucOnFill=0;
int eucOnRotate=0;

// clock division - using rest&slide+shift buttons
int clockDivChannel = 102;
byte clockCCVal[10] = {15,26,36,48,58,68,80,90,100,112};
byte clockVal[10] = {2,3,4,6,8,2,6,2,3,4};  //{2,3,4,6,8,12,16,24,32,48};
int clockNums = 10;
int clockCounter=0;

// gate length. changes automatically with clock division
int gateLengthChannel = 103;
byte gateLengthVal[10] = {40,30,20,15,12,9,6,6,5,5}; // {16,12,8,6,5,4,3,3,2,2}

// voicing - using tie+shift buttons
int voicingChannel = 18;
byte voicingCCVal[7] = {10,26,45,65,82,100,118};
byte voicingVal[7] = {4,5,3,15,6,1,2};  //{poly,cyclic,random,vel,sort,U1,U2};
int voicingNums = 7;
int voicingCounter=0;

// euclidean cc
int euclideanChannel = 107; // euclidean length. activates when becomes 1
byte euclideanCCVal[33] = {0,4,8,12,16,20,24,28,32,35,39,43,47,51,55,59,63,66,70,74,78,82,86,90,94,97,101,105,109,113,117,121,125};
byte euclideanVal[33] = {0,1,2,3,4,5,6,7,8,9,1,1,2,3,4,5,6,7,8,9,2,1,2,3,4,5,6,7,8,9,3,1,2};  // 0-32 steps length;
int euclideanNums = 33;
int euclideanCounter=0;

// 4051 Mux for CC Pots:
#define ccPin A0 // atmega
int ccPotChannels = 8;
#define addressA 10
#define addressB 11
#define addressC 12
int A = 0;      //Address pin A
int B = 0;      //Address pin B
int C = 0;      //Address pin C

//Define CC Pots
byte cc[] = {0, 0, 0, 0, 0, 0, 0, 0};
byte pot[] = {0, 0, 0, 0, 0, 0, 0, 0};
byte lastpot[] = {0, 0, 0, 0, 0, 0, 0, 0};
//Define cc number of each pot
byte midi_cc[] = {104, 105, 106, 25, 23, 27, 1, 5};
/*
                 {0,    1,   2,   3,  4,  5, 6, 7};

 104 - arp range
 105 - arp direction 
 106 - arp pattern
 27  - tuning system
 28  - trigger duration
 20  - legato
 23  - vibrato speed
 22  - vibrato range
 1   - mod wheel
 5   - portamento time
 25  - fine tuning
 71  - oscillator waveform
 102 - clock division
 103 - arp/seq gate length
 30  - trigger shape
 18  - voicing
 107 - eulidean length
 108 - eulidean fill
 109 - eulidean
 
 */

// midi selection button
#define midiButton 7 // mcpArray[1]
byte MidiButtonState = 0;
byte MidiButtonLastState = HIGH;
byte midiChannel = 0;  // Midi Channel 
int defMidi = 1; // default Midi channel
int numMidiChannels=4; // # of MIDI Channels, can be changed to 8 for controlling two Yarns from one Needles.

// for all-notes-off
int killState = 0;
const int killChannel = 123;

// step 7
#define wholeNotePin 5 // atmega
int wholeNoteState = 0;
int wholeNoteLastState = 0; 

// step 3
#define thirdNotePin 4 // atmega
int thirdNoteState = 0;
int thirdNoteLastState = 0;

// Legato
#define legatoPin 13 // atmega
int legatoState = 0;
int legatoLastState = 0;
int legatoCurrentState = HIGH;    
long time = 0;         // the last time the output pin was toggled
long debounce = 180;   // the debounce time, 

// Legato LED
#define legatoLed 3  // atmega

// Tie
#define tiePin A2 // atmega
#define tieChannel 112 // cc#
int tieState = 0;
int tiePushCounter = 0;   // counter for the number of button presses
int tieLastState = 0; 

// Rest
#define restPin 6 // atmega
#define restChannel 113 // #cc
int restState = 0;
int restPushCounter = 0;   // counter for the number of button presses
int restLastState = 0; 

// Slide
#define slidePin A1 // atmega
int slideState = 0;
int slidePushCounter = 0;   // counter for the number of button presses
int slideLastState = 0; 
int slideOn=0;

// Shift
#define shiftPin 5 // mcpArray[1]
#define shiftLedPin 6 // mcpArray[1]
int shiftState;
int shiftLastState = LOW;         
int turnoff;
//int state = 23;

//4T mode changes some CC values
#define fourTPin 2 // atmega
int fourTState = 0;
int fourTLastState = 0;

#define oscPin 9 // atmega
int oscState = 0;
int oscLastState = 0;
int oscLastMapped=0;

// Velocity Slider
#define velocityPin A3 // atmega
int velocityVal=0; 
int velocityState=0;

// Arp LED, Euc LED
#define arpLed 2 // mcpArray[1]
#define euclidean 7 // mcpArray[2]
int eucOn = 0;
int ccArp=0;

//// Extra Analog Ins. Uncomment to enable
//#define xtraAnalog A6 // atmega
//int xtraVal=0;
//int xtraValState=0;
//
//// Extra Analog IN for future use
//#define xtraAnalog7 A7 // atmega
//int xtraVal7=0;
//int xtraValState7=0;


//Keyboard on mcp0+mcp1 pins:
char notes[18]={0,1,2,3,4,5,6,7,8,9,10,11,12,13,14,15,16,17};   //pin setup for 18 buttons (mcp1&2)
boolean noteOn[18]={0,0,0,0,0,0,0,0,0,0,0,0,0,0,0,0,0,0};    //button state
boolean noteLast[18]={0,0,0,0,0,0,0,0,0,0,0,0,0,0,0,0,0,0};   //last button state
char noteCount=18;

// Octave keys
char changePins[2]={3,4}; // octave up/down mcpArray[1]
char octaveChanges[3]={12,-12,0}; //numbers for octave changing
//char singleChanges[3]={1,-1,0}; //numbers for half step changing
boolean changeButton[2]={0,0};  //octave button state
boolean changeButtonLast[2]={0,0};  //last octave button state

int keysBase=55;  //base for keyboard G2
int keysLast=keysBase;  //last keyboard base state
int changekeys(int a,int b){  //function to change key base
keysLast=a+b;
return(keysLast);
}

int storeChannel;
int ccMappedLastState=0;


void setup() {
// various
  pinMode(wholeNotePin, INPUT_PULLUP);
  pinMode(thirdNotePin, INPUT_PULLUP);
  pinMode(legatoPin, INPUT_PULLUP);
  pinMode(tiePin, INPUT_PULLUP);
  pinMode(restPin, INPUT_PULLUP);
  pinMode(slidePin, INPUT_PULLUP);
  pinMode(oscPin, INPUT_PULLUP);
  pinMode(fourTPin, INPUT_PULLUP);

// 4051 chip
  pinMode(addressA, OUTPUT);
  pinMode(addressB, OUTPUT);
  pinMode(addressC, OUTPUT);
  pinMode(ccPin, INPUT);

// MCP chip
  mcpArray[0].begin(0);
  mcpArray[1].begin(1);
  mcpArray[2].begin(2);

//octave buttons
  mcpArray[1].pinMode(changePins[0], INPUT);
  mcpArray[1].pullUp(changePins[0], HIGH); 
  mcpArray[1].pinMode(changePins[1], INPUT);
  mcpArray[1].pullUp(changePins[1], HIGH);  

// midi button
  mcpArray[1].pinMode(midiButton, INPUT);
  mcpArray[1].pullUp(midiButton, HIGH);  

// shift pin
  mcpArray[1].pinMode(shiftPin, INPUT);
  mcpArray[1].pullUp(shiftPin, HIGH);  
  mcpArray[1].pinMode(shiftLedPin, OUTPUT);

// Segment
 for (int i = 0; i < 7; i++) {
    mcpArray[2].pinMode(ones[i], OUTPUT);
    mcpArray[2].pinMode(tens[i], OUTPUT); 
  }
  mcpArray[2].pinMode(tensDP, OUTPUT); 
  pinMode(onesAnode, OUTPUT); 
  pinMode(tensAnode, OUTPUT); 
  //pinMode(tensDP, OUTPUT);    

  digitalWrite(onesAnode, LOW);
  digitalWrite(tensAnode, LOW); 

// Euclidean
  mcpArray[2].pinMode(euclidean, OUTPUT);

// Octave LEDs
  for (int i = 0; i < numberOfLED; i++) {  
    mcpArray[1].pinMode(ledPins[i], OUTPUT);
 } 
  
// Octave LED's center default
  mcpArray[1].digitalWrite(ledPins[3], HIGH); 

// keyboard 1-16
  for (int x = 0; x < 16; x++) {  
   mcpArray[0].pinMode(x, INPUT);
   mcpArray[0].pullUp(x, HIGH);   
 }
// keyboard 17&18
   mcpArray[1].pinMode(0, INPUT);
   mcpArray[1].pullUp(0, HIGH);  
   mcpArray[1].pinMode(1, INPUT);
   mcpArray[1].pullUp(1, HIGH);  

// Arp LED, 4T LED
  mcpArray[1].pinMode(arpLed, OUTPUT);
  pinMode(legatoLed, OUTPUT);

// Enable and launch MIDI
  pinMode(MIDI_ENABLE, OUTPUT);
  digitalWrite(MIDI_ENABLE, HIGH);
  MIDI.begin();
}


void loop() { 

// 7 Segment
MidiButtonState = mcpArray[1].digitalRead(midiButton);

if (midiChannel==0){
 for (int j=0; j < 7; j++) { 
    mcpArray[2].digitalWrite(ones[j], num_array[defMidi][j]);  
  } 
  midiChannel=1;
}


// Choose midi channel and display
  if(MidiButtonState && MidiButtonState != MidiButtonLastState)  // button latch, for debounce
  {
    if(midiChannel < numMidiChannels) // check count range and reset back to 0
      midiChannel += 1; //
    else
      midiChannel = 1;
    for (int j=0; j < 7; j++) { 
    mcpArray[2].digitalWrite(ones[j], num_array[midiChannel][j]);    
  } 
// keep tensAnode off until midi channel gets to 10  
if (midiChannel>9){
digitalWrite(tensAnode, HIGH); 
    for (int j=0; j < 7; j++) { 
    mcpArray[2].digitalWrite(tens[j], num_array[1][j]);   
    } 
} else {
  digitalWrite(tensAnode, HIGH);
  mcpArray[2].digitalWrite(tensDP, HIGH);
}

  if (killState==1){
    mcpArray[1].digitalWrite(shiftLedPin, HIGH);
    storeChannel = midiChannel-1;
    }
  } 
  MidiButtonLastState = MidiButtonState;

// Read velocity slider + xtras 
  velocityVal=analogRead(velocityPin);
  int velocityValMapped=map(velocityVal,0,1023,1,128); // velocity slider
  int oscMapped=map(velocityVal,0,1023,1,128); // for OSC slider
  int ccMapped=map(velocityVal,0,1023,0,127); // for JUNO
  int pitchMapped=map(velocityVal,0,1023,0,8000); // for JUNO


//// Extra Analog on Atmega ADC6. Uncomment to enable
//xtraVal=analogRead(xtraAnalog);
//int xtraValMapped=map(xtraVal,26,1023,0,127); // velocity slider
//    if (xtraValMapped != xtraValState){
//    MIDI.sendControlChange(4,xtraValMapped,midiChannel);
//    }
//xtraValState = xtraValMapped;
//
//// Extra Analog on Atmega ADC6
//xtraVal7=analogRead(xtraAnalog7);
//int xtraValMapped7=map(xtraVal7,26,1023,0,127); // velocity slider
//    if (xtraValMapped7 != xtraValState7){
//    MIDI.sendControlChange(2,xtraValMapped7,midiChannel);
//    }
//xtraValState7 = xtraValMapped7;

//limit keyboard from G-2 to C8
  keysLast = constrain(keysLast,7,103);             
  for(int i=0;i<2;i++){                 //loop for modifier keys
    changeButtonLast[i]=changeButton[i];        //update modifier key state
    changeButton[i]=mcpArray[1].digitalRead(changePins[i]);     //read state of modifier keys
      
//reset octaves - if modifier buttons 1 and 2 are pressed together simultaneously
  if(changeButton[0]&&changeButton[1]==HIGH){
      keysLast=keysBase; //revert keyboard base to C3

          // light up default center octave led
           for (int n=0; n < 7; n++){
              mcpArray[1].digitalWrite(ledPins[n], octaveLed_array[4][n]); 
           }
    }
      //change octaves - if modifier buttons 1 or 2 are pressed 
      if(changeButton[i]==HIGH&&changeButtonLast[i]!=changeButton[i]){
        //change keyboard base up or down in octaves
        changekeys(octaveChanges[i],keysLast);

        // hack - attempt to light off shift when note is latched
        if (turnoff==1&&killState==0&&storeChannel==midiChannel){
          mcpArray[1].digitalWrite(shiftLedPin, LOW);
        }
        // hack- need to remove once I figure out sending note-off when octave buttona are pressed which causes notes to stay on
        MIDI.sendControlChange(killChannel,0,midiChannel); 

      // light up correct octave led
       for (int j=0; j < 9; j++) { 
          if (keysLast==octaveNote_array[j]){
             for (int n=0; n < 7; n++){
               mcpArray[1].digitalWrite(ledPins[n], octaveLed_array[j][n]); 
             }
          }
       } 

    }
}

    
//loop for the 17 button keyboard
  for(char n=0;n<noteCount;n++){  
    noteOn[n]=mcpArray[(notes[n]>>4)].digitalRead(notes[n] & 0x0F);   // // forums.adafruit.com/viewtopic.php?f=25&t=28254  
    //   noteOn[n]=mcpArray0.digitalRead(notes[n]);                    //read state of keyboard
    if(noteOn[n]==HIGH&&noteLast[n]!=noteOn[n]){        //if a key(s) is pressed
      MIDI.sendNoteOn(keysLast+n,velocityValMapped,midiChannel);   //channel 1 MIDI note(s) ON with Pot Velocity value
      noteLast[n]=noteOn[n]; 
      killState=1; 
      turnoff=0;
      if (slideOn==1){ // turns "S" seg off
           digitalWrite(tensAnode, HIGH);
           slideOn=0;
      }
    } 
    if(noteLast[n]!=noteOn[n]){                     //if last keyboard state changes
      MIDI.sendNoteOff(keysLast+n,velocityValMapped,midiChannel);      //channel 1 MIDI note(s) OFF with Pot Velocity value
      noteLast[n]=noteOn[n];  
      turnoff=1;//update keyboard state
      killState=0;
      
    }
  }

// Display Velocity on Segment 0-9 only if OSC mode is off
int velocitySegVal=velocityVal/112;
if (abs(velocityVal - velocityState)>=4 && segOnStart!=0){  
  if (oscState==HIGH){ 
    mcpArray[2].digitalWrite(tensDP, HIGH);
    digitalWrite(tensAnode, LOW);
    for (int n=0; n < 7; n++){
        mcpArray[2].digitalWrite(tens[n], num_array[velocitySegVal][n]); 
     }
  }
  }
  velocityState = velocityVal;

// read the state button pins:
  tieState = digitalRead(tiePin);
  restState = digitalRead(restPin);
  slideState = digitalRead(slidePin);
  shiftState = mcpArray[1].digitalRead(shiftPin);
  wholeNoteState = digitalRead(wholeNotePin);
  thirdNoteState = digitalRead(thirdNotePin);
  legatoState = digitalRead(legatoPin);
  oscState = digitalRead(oscPin);
  fourTState = digitalRead(fourTPin);

if (midi_cc[2] == 106){ // if euclidean is off then use these buttons to step 3 or 7 - bigger rest and tie steps
 if (wholeNoteState != wholeNoteLastState) {
 if (wholeNoteState == LOW&&shiftState==HIGH) {
     MIDI.sendControlChange(tieChannel,127,midiChannel);
     MIDI.sendControlChange(tieChannel,127,midiChannel); 
     MIDI.sendControlChange(tieChannel,127,midiChannel); 
     
     mcpArray[2].digitalWrite(tensDP, HIGH);
     digitalWrite(tensAnode, LOW);
     for (int f=0; f < 7; f++) { 
        mcpArray[2].digitalWrite(tens[f], num_array[3][f]); 
     }
      slideOn=1;

}
  if (shiftState==LOW&&wholeNoteState == LOW){
      MIDI.sendControlChange(restChannel,127,midiChannel); 
      MIDI.sendControlChange(restChannel,127,midiChannel);
      MIDI.sendControlChange(restChannel,127,midiChannel); 
      
      mcpArray[2].digitalWrite(tensDP, LOW);
      digitalWrite(tensAnode, LOW);
      for (int f=0; f < 7; f++) { 
         mcpArray[2].digitalWrite(tens[f], num_array[3][f]); 
      }
    slideOn=1;    
  }     
}
wholeNoteLastState = wholeNoteState;

   
 if (thirdNoteState != thirdNoteLastState) {
 if (thirdNoteState == LOW&&shiftState==HIGH) {
     MIDI.sendControlChange(tieChannel,127,midiChannel);
     MIDI.sendControlChange(tieChannel,127,midiChannel); 
     MIDI.sendControlChange(tieChannel,127,midiChannel); 
     MIDI.sendControlChange(tieChannel,127,midiChannel);
     MIDI.sendControlChange(tieChannel,127,midiChannel); 
     MIDI.sendControlChange(tieChannel,127,midiChannel); 
     MIDI.sendControlChange(tieChannel,127,midiChannel); 

      mcpArray[2].digitalWrite(tensDP, HIGH);
      digitalWrite(tensAnode, LOW);
      for (int f=0; f < 7; f++) { 
        mcpArray[2].digitalWrite(tens[f], num_array[7][f]); 
      }
     slideOn=1;
}

 if (shiftState==LOW&&thirdNoteState == LOW){
      MIDI.sendControlChange(restChannel,127,midiChannel); 
      MIDI.sendControlChange(restChannel,127,midiChannel);
      MIDI.sendControlChange(restChannel,127,midiChannel); 
      MIDI.sendControlChange(restChannel,127,midiChannel); 
      MIDI.sendControlChange(restChannel,127,midiChannel);
      MIDI.sendControlChange(restChannel,127,midiChannel); 
      MIDI.sendControlChange(restChannel,127,midiChannel); 

      mcpArray[2].digitalWrite(tensDP, LOW);
      digitalWrite(tensAnode, LOW);
      for (int f=0; f < 7; f++) { 
          mcpArray[2].digitalWrite(tens[f], num_array[7][f]); 
      }
      slideOn=1;

}
}
   thirdNoteLastState = thirdNoteState;

///////////////////////////////////
}

if (midi_cc[2] == 108){ // if Euclidean is ON use the two buttons for plus/minus euclidean length, up to 32 steps
 if (wholeNoteState != wholeNoteLastState) {
  if (wholeNoteState == LOW){
if (euclideanCounter < euclideanNums-1){
      euclideanCounter++;
      } 
      else {
      euclideanCounter = 0;
      }
    MIDI.sendControlChange(euclideanChannel,euclideanCCVal[euclideanCounter],midiChannel); 
    digitalWrite(tensAnode, LOW);
    if (euclideanCounter==10||euclideanCounter==20||euclideanCounter==30){
    mcpArray[2].digitalWrite(tensDP, LOW);
    } else {
      mcpArray[2].digitalWrite(tensDP, HIGH);
    }
      for (int b=0; b < 7; b++) { 
      mcpArray[2].digitalWrite(tens[b], num_array[euclideanVal[euclideanCounter]][b]);  
      }
}
}
wholeNoteLastState = wholeNoteState;


if (thirdNoteState != thirdNoteLastState) {
  if (thirdNoteState == LOW){
if (euclideanCounter > 0){
      euclideanCounter--;
      } 
      else {
      euclideanCounter = 32;
      }
    MIDI.sendControlChange(euclideanChannel,euclideanCCVal[euclideanCounter],midiChannel); 
  digitalWrite(tensAnode, LOW);
      if (euclideanCounter==10||euclideanCounter==20||euclideanCounter==30){
    mcpArray[2].digitalWrite(tensDP, LOW);
    } else {
      mcpArray[2].digitalWrite(tensDP, HIGH);
    }
  for (int b=0; b < 7; b++) { 
    mcpArray[2].digitalWrite(tens[b], num_array[euclideanVal[euclideanCounter]][b]);  
  }
}
}
thirdNoteLastState = thirdNoteState;
}


//JUNO SPECIAL FUNCTIONS

 sysexValue[0][5] = ccMapped;
 sysexValue[1][5] = ccMapped;
 
if (ccMapped != ccMappedLastState){
  if (shiftState == LOW) { // shift + velocity slider controls cutoff
    MIDI.sendSysEx(7, sysexValue[0], true); // juno
  }
  if (restState == LOW) { // rest + velocity slider controls resonance
    MIDI.sendSysEx(7, sysexValue[1], true); // juno
  }
  if (slideState == LOW) { // slide + velocity slider controls pitchbend
    MIDI.sendPitchBend(pitchMapped,midiChannel); // both
  }
} 
ccMappedLastState=ccMapped;

//Tie:
if (tieState != tieLastState) {
    if (tieState == LOW) {
      mcpArray[2].digitalWrite(tensDP, HIGH);
        digitalWrite(tensAnode, LOW);

        for (int f=0; f < 7; f++) { 
        mcpArray[2].digitalWrite(tens[f], letter_array[14][f]); 
        }
      tiePushCounter++;
         MIDI.sendControlChange(tieChannel,127,midiChannel); // CC112, 127 Velocity, Channel 1. also turns nord chord memory on
    } 

     //clock div selection. every combo press advances clock Div array // also adjusts gate length automatically as defined in setup
    if (tieState == LOW&&shiftState==LOW){ 
     if (voicingCounter < voicingNums-1){
      voicingCounter++;
      } 
      else {
      voicingCounter = 0;
      }
    MIDI.sendControlChange(voicingChannel,voicingCCVal[voicingCounter],midiChannel); 

  mcpArray[2].digitalWrite(tensDP, HIGH);
  digitalWrite(tensAnode, LOW);
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

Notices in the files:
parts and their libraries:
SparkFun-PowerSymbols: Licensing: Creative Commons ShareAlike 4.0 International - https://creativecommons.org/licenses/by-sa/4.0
